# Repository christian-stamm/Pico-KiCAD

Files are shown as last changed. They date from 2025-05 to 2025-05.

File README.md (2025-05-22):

# Pico-KiCAD

The **DebugProbe** project aims to re-imagine Raspberry Pi Debug Probe.

## Anke (Debug Probe)

**Anke** is a 4-layer board intended to accommodate the popular Raspberry Pi RP2040 MCU with all required component to function identically to Raspberry Pi Debug Probe. The board is pin-compatible with Raspberry Pi Debug Probe and can be used with the same picoprobe SW.

Features:

- Very small form-factor of about 25x40mm.
- Raspberry Pi RP2040 MCU as a heart of the board.
- USB Type-C connector for power and communication.
- Several LEDs to indicate power and status.
- BOOTSEL button to enter the bootloader mode for flashing new picoprobe SW.
- Pin-compatible with Raspberry Pi Debug Probe.

## Bernd (RGB Panel ECU)

Bernd is a 4-layer board intended to drive 4x2 RGB Panels each consisting of 64x64 Pixel.

Features:

- Very small form-factor of about 60x60mm.
- Raspberry Pi RP2350B MCU as a heart of the board.
- USB Type-C connector for power and communication.
- BOOTSEL button to enter the bootloader mode for flashing new picoprobe SW.

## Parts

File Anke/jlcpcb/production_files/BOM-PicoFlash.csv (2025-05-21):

Comment | Designator | Footprint | LCSC | Quantity
470 | R1,R12,R2,R3,R4,R5,R6,R7 | R_0402_1005Metric | C11702 | 8
2u2 | C11,C4,C9 | C_0402_1005Metric | C12530 | 3
GREEN | D1,D6 | LED_0603_1608Metric | C12624 | 2
100nF | C10,C17,C18,C2,C3,C6,C7,C8 | C_0402_1005Metric | C1525 | 8
15pF | C19,C20 | C_0402_1005Metric | C1548 | 2
Conn_01x08_MountingPin | J2 | CONN-TH_SM08B-SRSS-TB-LF-SN | C160407 | 1
RP2040 | U2 | QFN-56-1EP_7x7mm_P0.4mm_EP3.2x3.2mm | C2040 | 1
12MHz | Y1 | CRYSTAL-SMD_4P-L3.2-W2.5-BL | C20625731 | 1
RED | D2,D5 | LED_0603_1608Metric | C2286 | 2
100nF | C1,C16 | C_0402_1005Metric | C23630 | 2
100R | R13,R14,R15,R16,R17,R18,R9 | R_0402_1005Metric | C25076 | 7
27R | R24,R25 | R_0402_1005Metric | C25100 | 2
10k | R19,R20 | R_0402_1005Metric | C25744 | 2
5k1 | R10,R11 | R_0402_1005Metric | C25905 | 2
CONN_USB | J10 | USB-C-SMD_TYPE-C-6PIN-2MD-073 | C2765186 | 1
W25Q16JVUXIQ | U4 | USON-8_L3.0-W2.0-P0.50-BL-EP | C2843335 | 1
TS-1089S-02526 | U5,U8 | SW-SMD_4P-L4.2-W3.3-P2.15-LS5.1 | C455282 | 2
AP2112K-3.3 | U1 | SOT-23-5 | C51118 | 1
74AUP1T17GWH | U3,U6 | TSSOP-5_L2.1-W1.3-P0.65-LS2.2-BR | C545951 | 2
22uF | C14,C15 | C_0603_1608Metric | C59461 | 2
YELLOW | D4,D7 | LED_0603_1608Metric | C72038 | 2

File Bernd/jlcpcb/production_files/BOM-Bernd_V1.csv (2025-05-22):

Comment | Designator | Footprint | LCSC | Quantity
470 | R10,R11,R12,R2 | R_0402_1005Metric | C11702 | 4
100n | C1,C11,C12,C13,C14,C15,C16,C17,C18,C2,C20,C21,C22,C23,C24,C25,C26,C29,C30,C5,C8 | C_0402_1005Metric | C1525 | 21
15p | C3,C4 | C_0402_1005Metric | C1548 | 2
10u | C19 | C_0402_1005Metric | C15525 | 1
Conn_01x04_Pin | J2 | JST_SH_BM04B-SRSS-TB_1x04-1MP_P1.00mm_Vertical | C160390 | 1
SM08B-SRSS-TB(LF)(SN) | U15,U3,U4 | CONN-TH_SM08B-SRSS-TB-LF-SN | C160407 | 3
ABM8-272-T3 | Y1 | CRYSTAL-SMD_4P-L3.2-W2.5-BL | C20625731 | 1
RED | D1 | LED_0603_1608Metric | C2286 | 1
4.7u | C10,C6,C7,C9 | C_0402_1005Metric | C23733 | 4
100 | R15,R4,R6 | R_0402_1005Metric | C25076 | 3
33 | R3 | R_0402_1005Metric | C25105 | 1
10K | R1,R5 | R_0402_1005Metric | C25744 | 2
5k1 | R13,R14 | R_0402_1005Metric | C25905 | 2
CONN_USB | J3 | USB-C-SMD_TYPE-C-6PIN-2MD-073 | C2765186 | 1
BH-00018 | U5,U6,U7,U8 | CONN-SMD_321016MG0CBK00A0 | C2829931 | 4
3.3u | L1 | IND-SMD_L2.0-W1.6_AOTA-B201610S3R3-101-T | C42411119 | 1
RP2350_80QFN | U1 | QFN-80_L10.0-W10.0-P0.40-TL-EP3.4 | C42415655 | 1
TS-1089S-02526 | U16,U17 | SW-SMD_4P-L4.2-W3.3-P2.15-LS5.1 | C455282 | 2
22uF | C27,C28 | C_0603_1608Metric | C45783 | 2
27 | R7,R8 | R_0402_1005Metric | C5151586 | 2
Jumper_3_Open | JP1 | PinHeader_1x03_P2.54mm_Vertical_SMD_Pin1Left | C5967212 | 1
AMS1117-3.3 | U13 | SOT-223-3_TabPin2 | C6186 | 1
W25Q64JWUUIQ | U2 | USON-8_L3.0-W2.0-P0.50-BL-EP | C6604692 | 1
TXS0108ERGYR | U10,U11,U12,U9 | VQFN-20_L4.6-W3.6-P0.50-BL-EP | C90706 | 4

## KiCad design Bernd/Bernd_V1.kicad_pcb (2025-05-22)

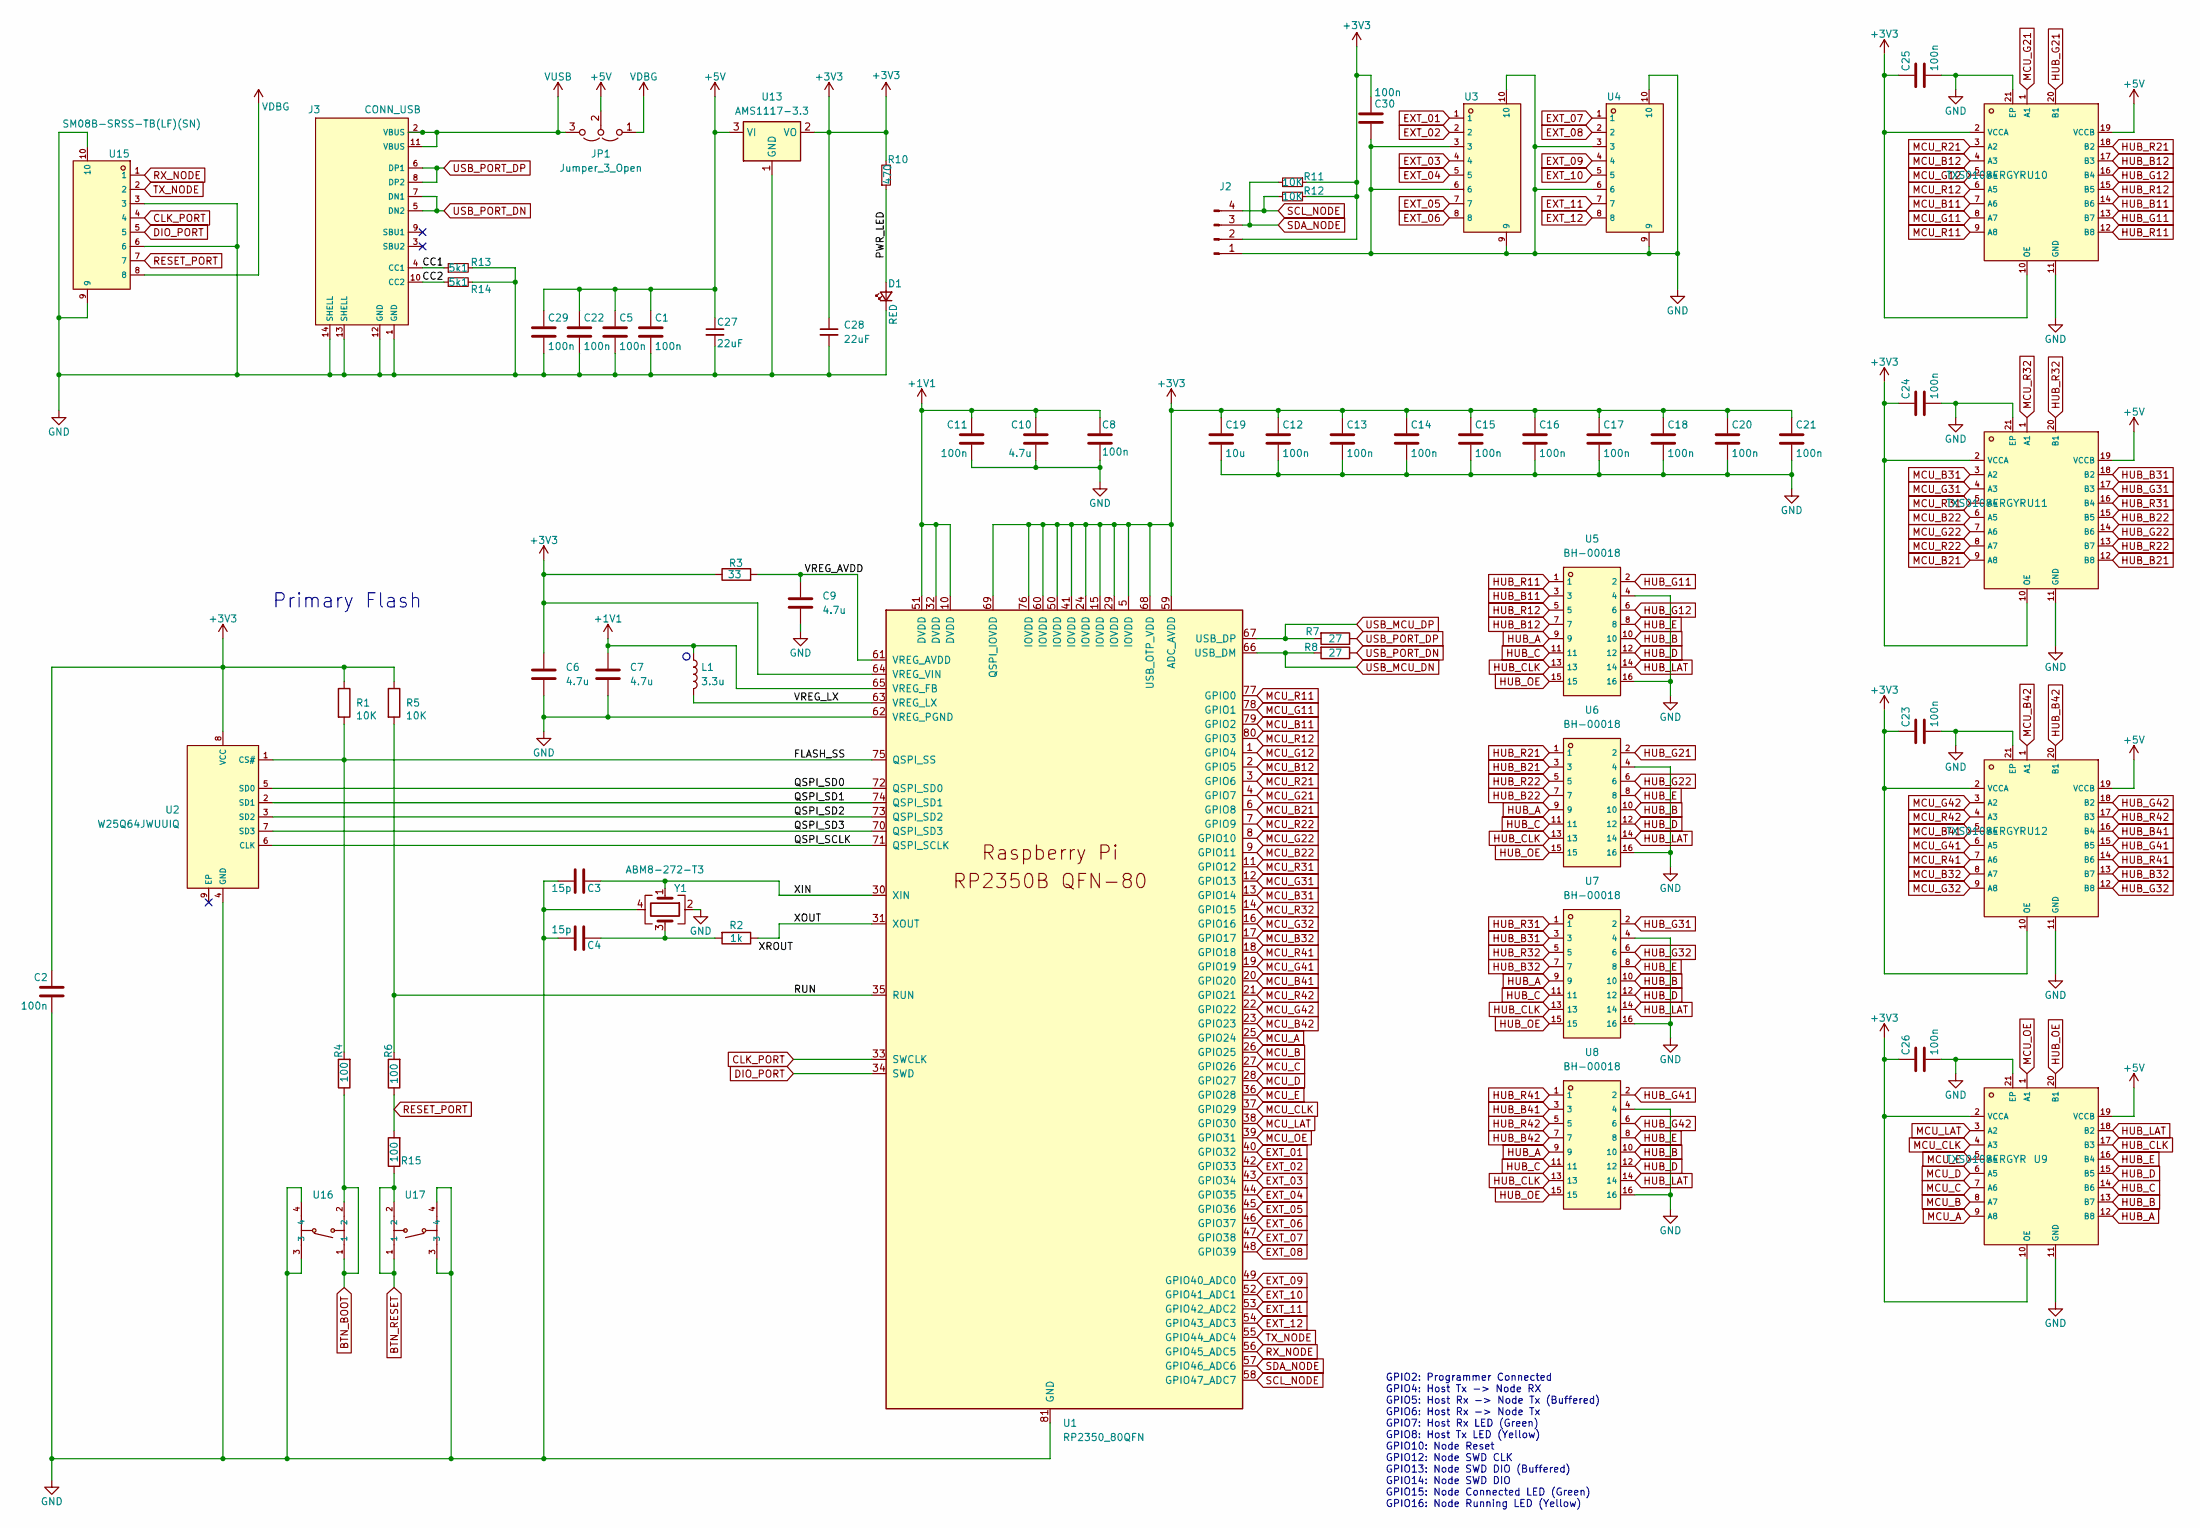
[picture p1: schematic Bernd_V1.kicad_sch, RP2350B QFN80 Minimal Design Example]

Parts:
C1, C2, C5, C8, C11, C12, C13, C14, C15, C16, C17, C18, C20, C21, C22, C23, C24, C25, C26, C29, C30: 100n; C_0402_1005Metric
C3, C4: 15p; C_0402_1005Metric
C6, C7: 4.7u; R_0402_1005Metric
C9, C10: 4.7u; C_0402_1005Metric
C19: 10u; C_0402_1005Metric
C27, C28: 22uF; C_0603_1608Metric; LCSC C45783
D1: RED; LED_0603_1608Metric; LCSC C2286
J2: Conn_01x04_Pin; JST_SH_BM04B-SRSS-TB_1x04-1MP_P1.00mm_Vertical; LCSC C160390
J3: CONN_USB; USB-C-SMD_TYPE-C-6PIN-2MD-073; LCSC C2765186
JP1: Jumper_3_Open; PinHeader_1x03_P2.54mm_Vertical_SMD_Pin1Left
L1: 3.3u; IND-SMD_L2.0-W1.6_AOTA-B201610S3R3-101-T
R1, R5: 10K; R_0402_1005Metric
R2: 1k; R_0402_1005Metric
R3: 33; R_0402_1005Metric
R4, R6, R15: 100; R_0402_1005Metric
R7, R8: 27; R_0402_1005Metric
R10: 470; R_0402_1005Metric; LCSC C11702
R11, R12: 10K; R_0402_1005Metric; LCSC C11702
R13, R14: 5k1; R_0402_1005Metric; LCSC C25905
U1: RP2350_80QFN; QFN-80_L10.0-W10.0-P0.40-TL-EP3.4
U2: W25Q64JWUUIQ; USON-8_L3.0-W2.0-P0.50-BL-EP; LCSC C6604692
U3, U4, U15: SM08B-SRSS-TB(LF)(SN); CONN-TH_SM08B-SRSS-TB-LF-SN; LCSC C160407
U5, U6, U7, U8: BH-00018; CONN-SMD_321016MG0CBK00A0; LCSC C2829931
U9, U10, U11, U12: TXS0108ERGYR; VQFN-20_L4.6-W3.6-P0.50-BL-EP; LCSC C90706
U13: AMS1117-3.3; SOT-223-3_TabPin2
U16, U17: TS-1089S-02526; SW-SMD_4P-L4.2-W3.3-P2.15-LS5.1; LCSC C455282
Y1: ABM8-272-T3; CRYSTAL-SMD_4P-L3.2-W2.5-BL

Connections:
+1V1: C7.1, C8.1, C10.1, C11.1, L1.1, U1.10 (DVDD), U1.32 (DVDD), U1.51 (DVDD), U1.65 (VREG_FB)
+3V3: C2.1, C6.1, C12.1, C13.1, C14.1, C15.1, C16.1, C17.1, C18.1, C19.1, C20.1, C21.1, C23.1, C24.1, C25.1, C26.1, C28.1, C30.1, J2.2, R1.1, R3.1, R5.1, R10.2, R11.1, R12.1, U1.5 (IOVDD), U1.15 (IOVDD), U1.24 (IOVDD), U1.29 (IOVDD), U1.41 (IOVDD), U1.50 (IOVDD), U1.59 (ADC_AVDD), U1.60 (IOVDD), U1.64 (VREG_VIN), U1.68 (USB_OTP_VDD), U1.69 (QSPI_IOVDD), U1.76 (IOVDD), U2.8 (VCC), U9.2 (VCCA), U9.10 (OE), U10.2 (VCCA), U10.10 (OE), U11.2 (VCCA), U11.10 (OE), U12.2 (VCCA), U12.10 (OE), U13.2 (VO)
+5V: C1.1, C5.1, C22.1, C27.1, C29.1, JP1.2 (C), U9.19 (VCCB), U10.19 (VCCB), U11.19 (VCCB), U12.19 (VCCB), U13.3 (VI)
/CC1: J3.4 (CC1), R13.1
/CC2: J3.10 (CC2), R14.1
/FLASH_SS: R1.2, R4.2, U1.75 (QSPI_SS), U2.1 (CS#)
/PWR_LED: D1.2 (A), R10.1
/QSPI_SCLK: U1.71 (QSPI_SCLK), U2.6 (CLK)
/QSPI_SD0: U1.72 (QSPI_SD0), U2.5 (SD0)
/QSPI_SD1: U1.74 (QSPI_SD1), U2.2 (SD1)
/QSPI_SD2: U1.73 (QSPI_SD2), U2.3 (SD2)
/QSPI_SD3: U1.70 (QSPI_SD3), U2.7 (SD3)
/RUN: R5.2, R6.2, U1.35 (RUN)
/VREG_AVDD: C9.1, R3.2, U1.61 (VREG_AVDD)
/VREG_LX: L1.2, U1.63 (VREG_LX)
/XIN: C3.1, U1.30 (XIN), Y1.1
/XOUT: R2.1, U1.31 (XOUT)
BTN_BOOT: R4.1, U16.1, U16.2
BTN_RESET: R15.1, U17.1, U17.2
CLK_PORT: U1.33 (SWCLK), U15.4
DIO_PORT: U1.34 (SWD), U15.5
EXT_01: U1.40 (GPIO32), U3.1
EXT_02: U1.42 (GPIO33), U3.2
EXT_03: U1.43 (GPIO34), U3.4
EXT_04: U1.44 (GPIO35), U3.5
EXT_05: U1.45 (GPIO36), U3.7
EXT_06: U1.46 (GPIO37), U3.8
EXT_07: U1.47 (GPIO38), U4.1
EXT_08: U1.48 (GPIO39), U4.2
EXT_09: U1.49 (GPIO40_ADC0), U4.4
EXT_10: U1.52 (GPIO41_ADC1), U4.5
EXT_11: U1.53 (GPIO42_ADC2), U4.7
EXT_12: U1.54 (GPIO43_ADC3), U4.8
GND: C1.2, C2.2, C3.2, C4.2, C5.2, C6.2, C7.2, C8.2, C9.2, C10.2, C11.2, C12.2, C13.2, C14.2, C15.2, C16.2, C17.2, C18.2, C19.2, C20.2, C21.2, C22.2, C23.2, C24.2, C25.2, C26.2, C27.2, C28.2, C29.2, C30.2, D1.1 (K), J2.1, J3.1 (GND), J3.12 (GND), J3.13 (SHELL), J3.14 (SHELL), R13.2, R14.2, U1.62 (VREG_PGND), U1.81 (GND), U2.4 (GND), U3.3, U3.6, U3.9, U3.10, U4.3, U4.6, U4.9, U4.10, U5.4, U5.16, U6.4, U6.16, U7.4, U7.16, U8.4, U8.16, U9.11 (GND), U9.21 (EP), U10.11 (GND), U10.21 (EP), U11.11 (GND), U11.21 (EP), U12.11 (GND), U12.21 (EP), U13.1 (GND), U15.3, U15.6, U15.9, U15.10, U16.3, U16.4, U17.3, U17.4, Y1.2, Y1.4
HUB_A: U5.9, U6.9, U7.9, U8.9, U9.12 (B8)
HUB_B: U5.10, U6.10, U7.10, U8.10, U9.13 (B7)
HUB_B11: U5.3, U10.14 (B6)
HUB_B12: U5.7, U10.17 (B3)
HUB_B21: U6.3, U11.12 (B8)
HUB_B22: U6.7, U11.15 (B5)
HUB_B31: U7.3, U11.18 (B2)
HUB_B32: U7.7, U12.13 (B7)
HUB_B41: U8.3, U12.16 (B4)
HUB_B42: U8.7, U12.20 (B1)
HUB_C: U5.11, U6.11, U7.11, U8.11, U9.14 (B6)
HUB_CLK: U5.13, U6.13, U7.13, U8.13, U9.17 (B3)
HUB_D: U5.12, U6.12, U7.12, U8.12, U9.15 (B5)
HUB_E: U5.8, U6.8, U7.8, U8.8, U9.16 (B4)
HUB_G11: U5.2, U10.13 (B7)
HUB_G12: U5.6, U10.16 (B4)
HUB_G21: U6.2, U10.20 (B1)
HUB_G22: U6.6, U11.14 (B6)
HUB_G31: U7.2, U11.17 (B3)
HUB_G32: U7.6, U12.12 (B8)
HUB_G41: U8.2, U12.15 (B5)
HUB_G42: U8.6, U12.18 (B2)
HUB_LAT: U5.14, U6.14, U7.14, U8.14, U9.18 (B2)
HUB_OE: U5.15, U6.15, U7.15, U8.15, U9.20 (B1)
HUB_R11: U5.1, U10.12 (B8)
HUB_R12: U5.5, U10.15 (B5)
HUB_R21: U6.1, U10.18 (B2)
HUB_R22: U6.5, U11.13 (B7)
HUB_R31: U7.1, U11.16 (B4)
HUB_R32: U7.5, U11.20 (B1)
HUB_R41: U8.1, U12.14 (B6)
HUB_R42: U8.5, U12.17 (B3)
MCU_A: U1.25 (GPIO24), U9.9 (A8)
MCU_B: U1.26 (GPIO25), U9.8 (A7)
MCU_B11: U1.79 (GPIO2), U10.7 (A6)
MCU_B12: U1.2 (GPIO5), U10.4 (A3)
MCU_B21: U1.6 (GPIO8), U11.9 (A8)
MCU_B22: U1.9 (GPIO11), U11.6 (A5)
MCU_B31: U1.13 (GPIO14), U11.3 (A2)
MCU_B32: U1.17 (GPIO17), U12.8 (A7)
MCU_B41: U1.20 (GPIO20), U12.5 (A4)
MCU_B42: U1.23 (GPIO23), U12.1 (A1)
MCU_C: U1.27 (GPIO26), U9.7 (A6)
MCU_CLK: U1.37 (GPIO29), U9.4 (A3)
MCU_D: U1.28 (GPIO27), U9.6 (A5)
MCU_E: U1.36 (GPIO28), U9.5 (A4)
MCU_G11: U1.78 (GPIO1), U10.8 (A7)
MCU_G12: U1.1 (GPIO4), U10.5 (A4)
MCU_G21: U1.4 (GPIO7), U10.1 (A1)
MCU_G22: U1.8 (GPIO10), U11.7 (A6)
MCU_G31: U1.12 (GPIO13), U11.4 (A3)
MCU_G32: U1.16 (GPIO16), U12.9 (A8)
MCU_G41: U1.19 (GPIO19), U12.6 (A5)
MCU_G42: U1.22 (GPIO22), U12.3 (A2)
MCU_LAT: U1.38 (GPIO30), U9.3 (A2)
MCU_OE: U1.39 (GPIO31), U9.1 (A1)
MCU_R11: U1.77 (GPIO0), U10.9 (A8)
MCU_R12: U1.80 (GPIO3), U10.6 (A5)
MCU_R21: U1.3 (GPIO6), U10.3 (A2)
MCU_R22: U1.7 (GPIO9), U11.8 (A7)
MCU_R31: U1.11 (GPIO12), U11.5 (A4)
MCU_R32: U1.14 (GPIO15), U11.1 (A1)
MCU_R41: U1.18 (GPIO18), U12.7 (A6)
MCU_R42: U1.21 (GPIO21), U12.4 (A3)
unnamed: C4.1, R2.2, Y1.3
RESET_PORT: R6.1, R15.2, U15.7
RX_NODE: U1.56 (GPIO45_ADC5), U15.1
SCL_NODE: J2.4, R12.2, U1.58 (GPIO47_ADC7)
SDA_NODE: J2.3, R11.2, U1.57 (GPIO46_ADC6)
TX_NODE: U1.55 (GPIO44_ADC4), U15.2
USB_MCU_DN: R8.2, U1.66 (USB_DM)
USB_MCU_DP: R7.2, U1.67 (USB_DP)
USB_PORT_DN: J3.5 (DN2), J3.7 (DN1), R8.1
USB_PORT_DP: J3.6 (DP1), J3.8 (DP2), R7.1
VDBG: JP1.1 (A), U15.8
VUSB: J3.2 (VBUS), J3.11 (VBUS), JP1.3 (B)

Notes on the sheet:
Primary Flash
GPIO2: Programmer Connected GPIO4: Host Tx -> Node RX GPIO5: Host Rx -> Node Tx (Buffered) GPIO6: Host Rx -> Node Tx GPIO7: Host Rx LED (Green) GPIO8: Host Tx LED (Yellow) GPIO10: Node Reset GPIO12: Node SWD CLK GPIO13: Node SWD DIO (Buffered) GPIO14: Node SWD DIO GPIO15: Node Connected LED (Green)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

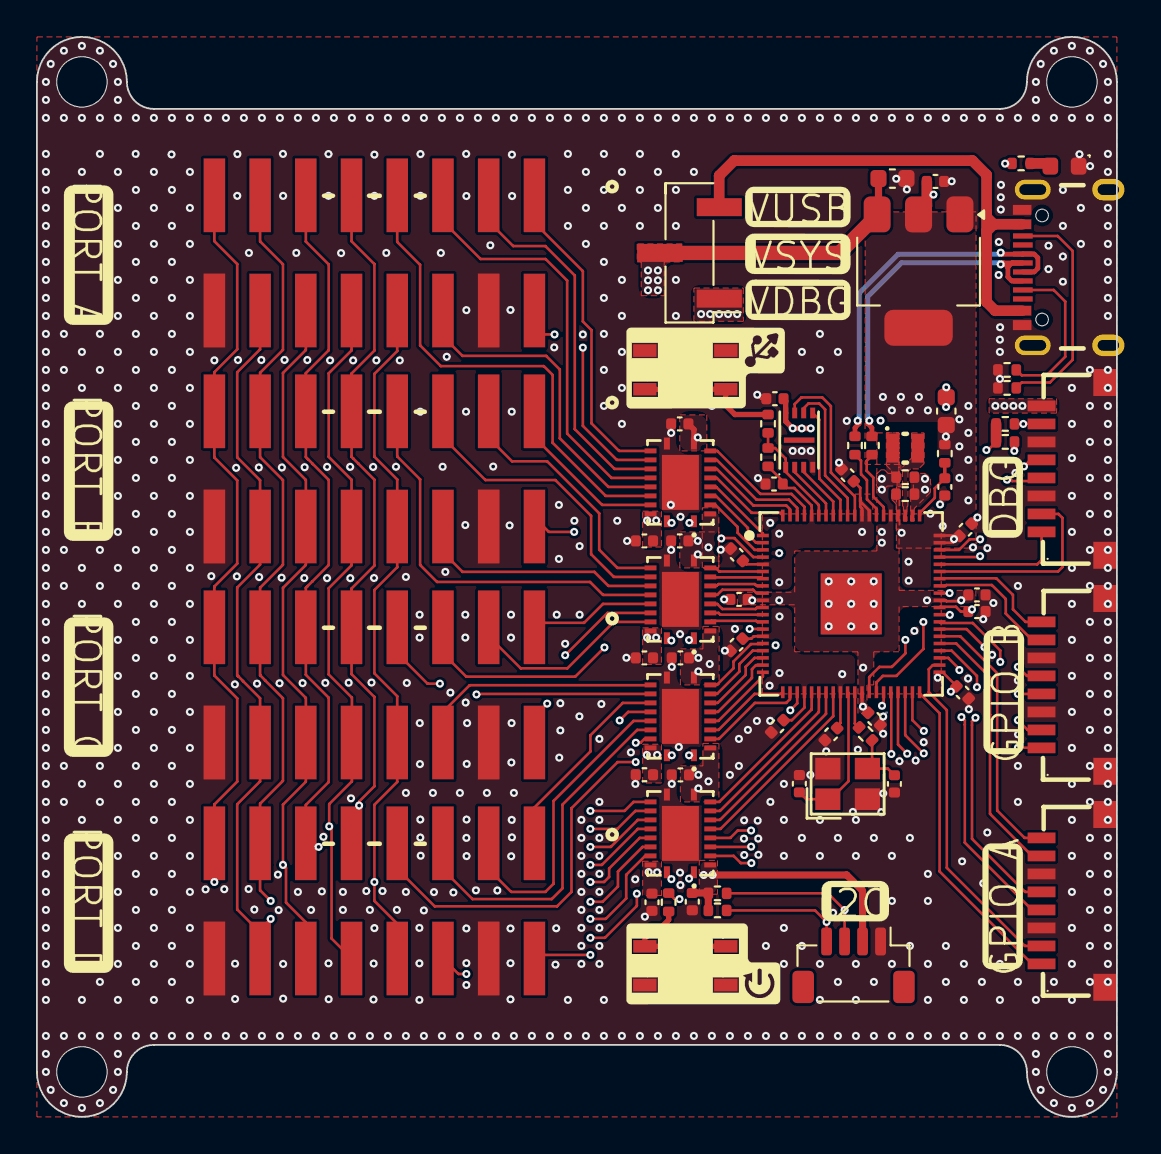
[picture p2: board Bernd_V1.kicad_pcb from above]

Board: 4 copper layers, 60.0 x 60.0 mm, 66 parts (0 on the bottom side), 110 nets.

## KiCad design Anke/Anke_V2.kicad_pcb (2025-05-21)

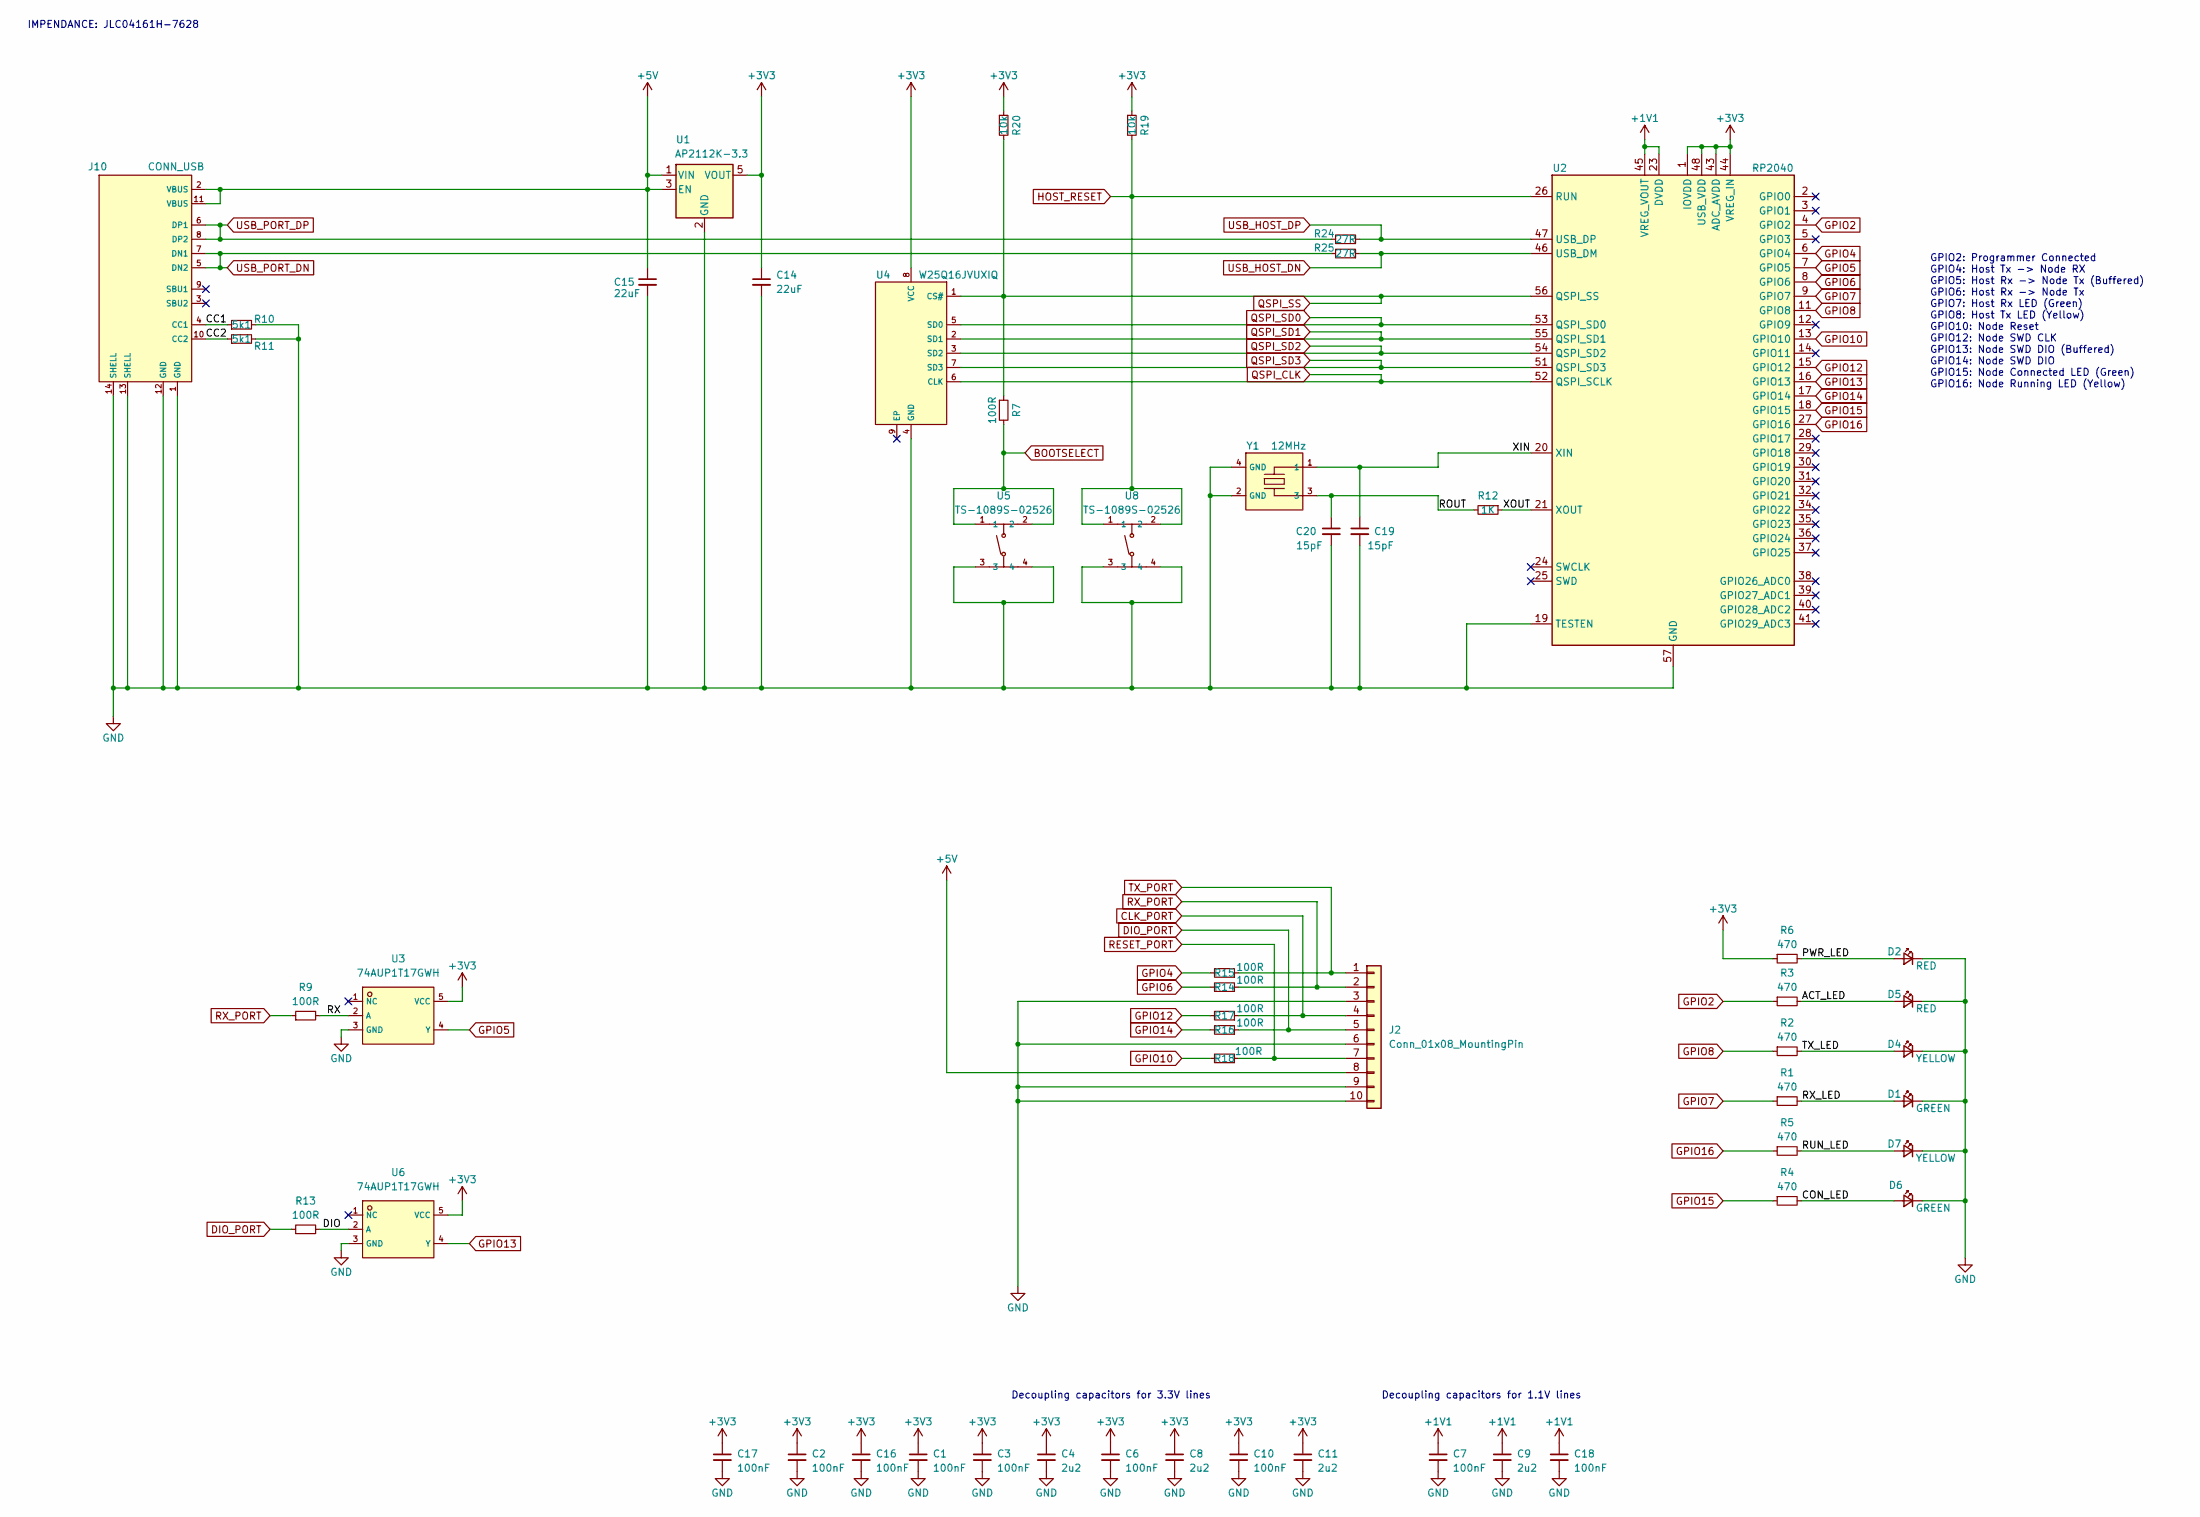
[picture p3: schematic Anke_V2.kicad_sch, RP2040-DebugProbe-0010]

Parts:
C1, C16: 100nF; C_0402_1005Metric; LCSC C23630
C2, C3, C6, C7, C10, C17, C18: 100nF; C_0402_1005Metric; LCSC C1525
C4, C9, C11: 2u2; C_0402_1005Metric; LCSC C12530
C8: 2u2; C_0402_1005Metric; LCSC C1525
C14, C15: 22uF; C_0603_1608Metric; LCSC C59461
C19, C20: 15pF; C_0402_1005Metric; LCSC C1548
D1, D6: GREEN; LED_0603_1608Metric; LCSC C12624
D2, D5: RED; LED_0603_1608Metric; LCSC C2286
D4, D7: YELLOW; LED_0603_1608Metric; LCSC C72038
J2: Conn_01x08_MountingPin; CONN-TH_SM08B-SRSS-TB-LF-SN; LCSC C160407
J10: CONN_USB; USB-C-SMD_TYPE-C-6PIN-2MD-073; LCSC C2765186
R1, R2, R3, R4, R5, R6: 470; R_0402_1005Metric; LCSC C11702
R7: 100R; R_0402_1005Metric; LCSC C11702
R9, R13, R14, R15, R16, R17, R18: 100R; R_0402_1005Metric; LCSC C25076
R10, R11: 5k1; R_0402_1005Metric; LCSC C25905
R12: 1K; R_0402_1005Metric; LCSC C11702
R19, R20: 10k; R_0402_1005Metric; LCSC C25744
R24, R25: 27R; R_0402_1005Metric; LCSC C25100
U1: AP2112K-3.3; SOT-23-5; LCSC C51118
U2: RP2040; QFN-56-1EP_7x7mm_P0.4mm_EP3.2x3.2mm; LCSC C2040
U3, U6: 74AUP1T17GWH; TSSOP-5_L2.1-W1.3-P0.65-LS2.2-BR; LCSC C545951
U4: W25Q16JVUXIQ; USON-8_L3.0-W2.0-P0.50-BL-EP; LCSC C2843335
U5, U8: TS-1089S-02526; SW-SMD_4P-L4.2-W3.3-P2.15-LS5.1; LCSC C455282
Y1: 12MHz; CRYSTAL-SMD_4P-L3.2-W2.5-BL; LCSC C20625731

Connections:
+1V1: C7.1, C9.1, C18.1, U2.23 (DVDD), U2.45 (VREG_VOUT), U2.50 (DVDD)
+3V3: C1.1, C2.1, C3.1, C4.1, C6.1, C8.1, C10.1, C11.1, C14.1, C16.1, C17.1, R6.1, R19.1, R20.1, U1.5 (VOUT), U2.1 (IOVDD), U2.10 (IOVDD), U2.22 (IOVDD), U2.33 (IOVDD), U2.42 (IOVDD), U2.43 (ADC_AVDD), U2.44 (VREG_IN), U2.48 (USB_VDD), U2.49 (IOVDD), U3.5 (VCC), U4.8 (VCC), U6.5 (VCC)
+5V: C15.1, J2.8, J10.2 (VBUS), J10.11 (VBUS), U1.1 (VIN), U1.3 (EN)
/ACT_LED: D5.2 (A), R3.2
/CC1: J10.4 (CC1), R10.1
/CC2: J10.10 (CC2), R11.1
/CON_LED: D6.2 (A), R4.2
/DIO: R13.2, U6.2 (A)
/PWR_LED: D2.2 (A), R6.2
/ROUT: C20.1, R12.2, Y1.3
/RUN_LED: D7.2 (A), R5.2
/RX: R9.2, U3.2 (A)
/RX_LED: D1.2 (A), R1.2
/TX_LED: D4.2 (A), R2.2
/XIN: C19.1, U2.20 (XIN), Y1.1
/XOUT: R12.1, U2.21 (XOUT)
BOOTSELECT: R7.2, U5.1, U5.2
CLK_PORT: J2.4, R17.1
DIO_PORT: J2.5, R13.1, R16.1
GND: C1.2, C2.2, C3.2, C4.2, C6.2, C7.2, C8.2, C9.2, C10.2, C11.2, C14.2, C15.2, C16.2, C17.2, C18.2, C19.2, C20.2, D1.1 (K), D2.1 (K), D4.1 (K), D5.1 (K), D6.1 (K), D7.1 (K), J2.3, J2.6, J2.9, J2.10, J10.1 (GND), J10.12 (GND), J10.13 (SHELL), J10.14 (SHELL), R10.2, R11.2, U1.2 (GND), U2.19 (TESTEN), U2.57 (GND), U3.3 (GND), U4.4 (GND), U5.3, U5.4, U6.3 (GND), U8.3, U8.4, Y1.2 (GND), Y1.4 (GND)
GPIO2: R3.1, U2.4 (GPIO2)
GPIO4: R15.2, U2.6 (GPIO4)
GPIO5: U2.7 (GPIO5), U3.4 (Y)
GPIO6: R14.2, U2.8 (GPIO6)
GPIO7: R1.1, U2.9 (GPIO7)
GPIO8: R2.1, U2.11 (GPIO8)
GPIO10: R18.2, U2.13 (GPIO10)
GPIO12: R17.2, U2.15 (GPIO12)
GPIO13: U2.16 (GPIO13), U6.4 (Y)
GPIO14: R16.2, U2.17 (GPIO14)
GPIO15: R4.1, U2.18 (GPIO15)
GPIO16: R5.1, U2.27 (GPIO16)
HOST_RESET: R19.2, U2.26 (RUN), U8.1, U8.2
QSPI_CLK: U2.52 (QSPI_SCLK), U4.6 (CLK)
QSPI_SD0: U2.53 (QSPI_SD0), U4.5 (SD0)
QSPI_SD1: U2.55 (QSPI_SD1), U4.2 (SD1)
QSPI_SD2: U2.54 (QSPI_SD2), U4.3 (SD2)
QSPI_SD3: U2.51 (QSPI_SD3), U4.7 (SD3)
QSPI_SS: R7.1, R20.2, U2.56 (QSPI_SS), U4.1 (CS#)
RESET_PORT: J2.7, R18.1
RX_PORT: J2.2, R9.1, R14.1
TX_PORT: J2.1, R15.1
USB_HOST_DN: R25.1, U2.46 (USB_DM)
USB_HOST_DP: R24.1, U2.47 (USB_DP)
USB_PORT_DN: J10.5 (DN2), J10.7 (DN1), R25.2
USB_PORT_DP: J10.6 (DP1), J10.8 (DP2), R24.2

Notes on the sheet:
GPIO2: Programmer Connected GPIO4: Host Tx -> Node RX GPIO5: Host Rx -> Node Tx (Buffered) GPIO6: Host Rx -> Node Tx GPIO7: Host Rx LED (Green) GPIO8: Host Tx LED (Yellow) GPIO10: Node Reset GPIO12: Node SWD CLK GPIO13: Node SWD DIO (Buffered) GPIO14: Node SWD DIO GPIO15: Node Connected LED (Green)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
Decoupling capacitors for 3.3V lines
Decoupling capacitors for 1.1V lines
IMPENDANCE: JLC04161H-7628

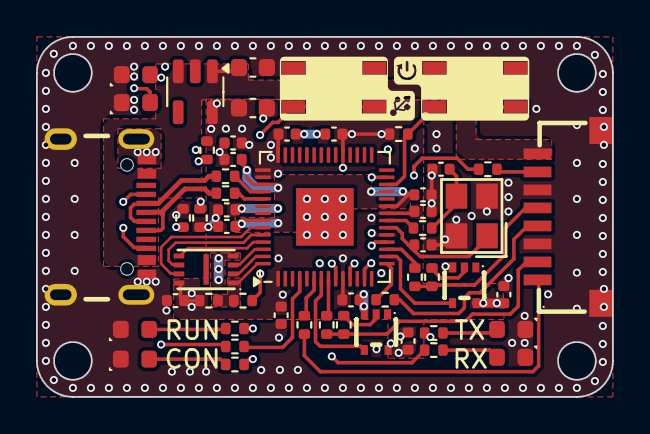
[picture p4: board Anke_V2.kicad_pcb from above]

Board: 4 copper layers, 32.0 x 20.0 mm, 54 parts (0 on the bottom side), 46 nets.

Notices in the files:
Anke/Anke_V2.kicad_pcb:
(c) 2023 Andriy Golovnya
